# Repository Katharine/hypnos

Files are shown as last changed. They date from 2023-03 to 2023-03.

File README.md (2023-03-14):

Project Hypnos
==============

A hardware controller for the Eight Sleep sleep mattress - because controlling your bed with a phone is a pain.

Turn a knob to adjust the temperature, press the knob to turn it on or off, or to turn off the alarm. Simple!



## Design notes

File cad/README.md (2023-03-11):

# Hypnos CAD files

They're on OnShape, [over here](https://cad.onshape.com/documents/eb943bd92382fa15c7f34176/w/b598a4b6743600d12fabdcd6/e/ee163424c4e488bc4fefc6ba).

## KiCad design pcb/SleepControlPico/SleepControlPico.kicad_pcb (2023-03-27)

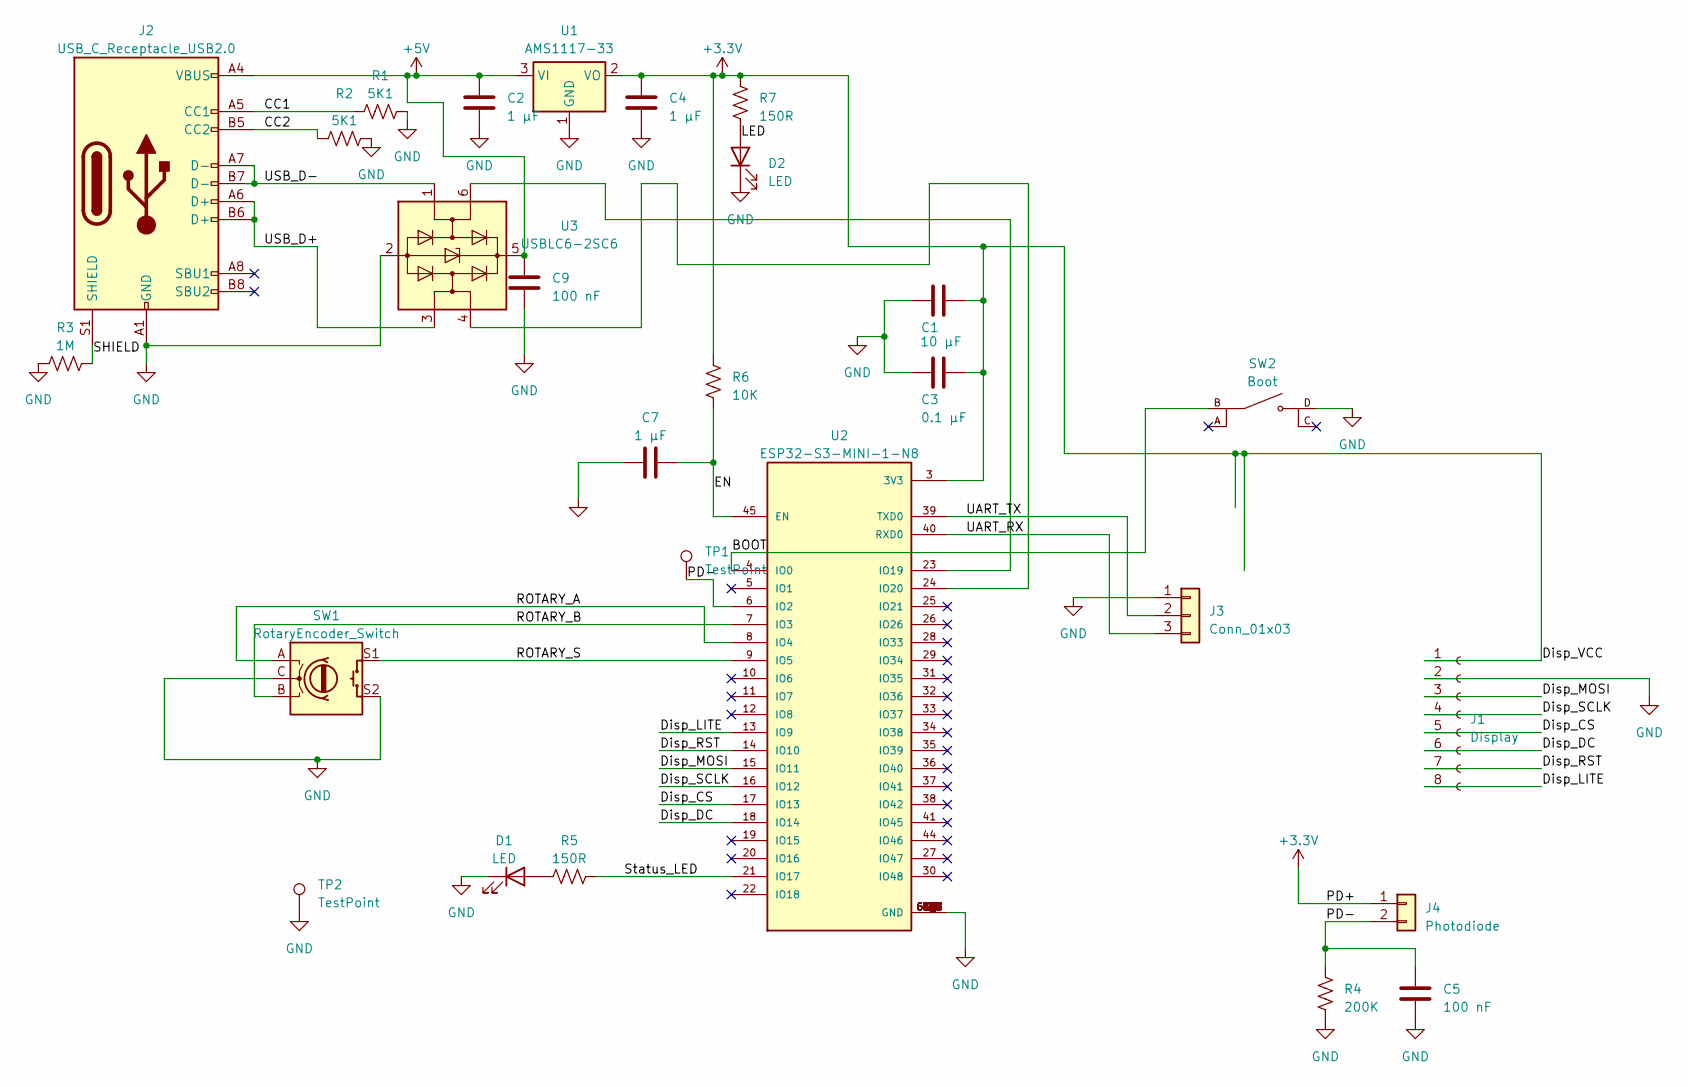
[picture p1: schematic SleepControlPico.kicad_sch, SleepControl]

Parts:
C1: 10 µF; C_0603_1608Metric; LCSC Part # C96446
C2, C4, C7: 1 µF; C_0402_1005Metric; LCSC Part # C52923
C3: 0.1 µF; C_0402_1005Metric; LCSC Part # C307331
C5, C9: 100 nF; C_0402_1005Metric; LCSC Part # C307331
D1, D2: LED; LED_0603_1608Metric; LCSC Part # C2286
J1: Display; JST-B8B-ZR-0; LCSC Part # C493145
J2: USB_C_Receptacle_USB2.0; USB_C_Receptacle_G-Switch_GT-USB-7010ASV; LCSC Part # C2988369
J3: Conn_01x03; PinHeader_1x03_P2.54mm_Horizontal; LCSC Part # C2935928
J4: Photodiode; JST_PH_B2B-PH-K_1x02_P2.00mm_Vertical; LCSC Part # C131337
R1, R2: 5K1; R_0603_1608Metric; LCSC Part # C23186
R3: 1M; R_0603_1608Metric; LCSC Part # C22935
R4: 200K; R_Axial_DIN0207_L6.3mm_D2.5mm_P7.62mm_Horizontal; LCSC Part # C58614
R5: 150R; R_0402_1005Metric; LCSC Part # C25133
R6: 10K; R_0603_1608Metric; LCSC Part # C25804
R7: 150R; R_0402_1005Metric; LCSC Part # C25082
SW1: RotaryEncoder_Switch; Bourns-PEC11R-4020F-S0012-MFG; LCSC Part # C143790
SW2: Boot; SW_TS-1187A-B-A-B; PARTREV A0; LCSC Part # C318884
TP1, TP2: TestPoint; TestPoint_Pad_D1.0mm
U1: AMS1117-33; SOT-223-3_TabPin2; LCSC Part # C6186
U2: ESP32-S3-MINI-1-N8; XCVR_ESP32-S3-MINI-1-N8; PARTREV v0.6; LCSC Part # C2913206
U3: USBLC6-2SC6; SOT-23-6; LCSC Part # C7519

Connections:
+3.3V: C1.1, C3.1, C4.1, J1.1, J4.1, R6.1, R7.1, U1.2 (VO), U2.3 (3V3)
+5V: C2.1, C9.2, J2.A4 (VBUS), J2.A9 (VBUS), J2.B4 (VBUS), J2.B9 (VBUS), U1.3 (VI), U3.5 (VBUS)
/BOOT: SW2.B, U2.4 (IO0)
/CC1: J2.A5 (CC1), R1.1
/CC2: J2.B5 (CC2), R2.1
/Disp_CS: J1.5, U2.17 (IO13)
/Disp_DC: J1.6, U2.18 (IO14)
/Disp_LITE: J1.8, U2.13 (IO9)
/Disp_MOSI: J1.3, U2.15 (IO11)
/Disp_RST: J1.7, U2.14 (IO10)
/Disp_SCLK: J1.4, U2.16 (IO12)
/EN: C7.2, R6.2, U2.45 (EN)
/PD-: C5.2, J4.2, R4.1, TP1.1, U2.6 (IO2)
/ROTARY_A: SW1.A, U2.8 (IO4)
/ROTARY_B: SW1.B, U2.7 (IO3)
/ROTARY_S: SW1.S1, U2.9 (IO5)
/SHIELD: J2.S1 (SHIELD), R3.1
/Status_LED: R5.2, U2.21 (IO17)
/UART_RX: J3.3, U2.40 (RXD0)
/UART_TX: J3.2, U2.39 (TXD0)
/USB_D+: J2.A6 (D+), J2.B6 (D+), U3.3 (I/O2)
/USB_D-: J2.A7 (D-), J2.B7 (D-), U3.1 (I/O1)
GND: C1.2, C2.2, C3.2, C4.2, C5.1, C7.1, C9.1, D1.1 (K), D2.1 (K), J1.2, J2.A1 (GND), J2.A12 (GND), J2.B1 (GND), J2.B12 (GND), J3.1, R1.2, R2.2, R3.2, R4.2, SW1.C, SW1.S2, SW2.D, TP2.1, U1.1 (GND), U2.1 (GND), U2.2 (GND), U2.42 (GND), U2.43 (GND), U2.46 (GND), U2.47 (GND), U2.48 (GND), U2.49 (GND), U2.50 (GND), U2.51 (GND), U2.52 (GND), U2.53 (GND), U2.54 (GND), U2.55 (GND), U2.56 (GND), U2.57 (GND), U2.58 (GND), U2.59 (GND), U2.60 (GND), U2.61 (GND), U2.61_1 (GND), U2.61_2 (GND), U2.61_3 (GND), U2.61_4 (GND), U2.61_5 (GND), U2.61_6 (GND), U2.61_7 (GND), U2.61_8 (GND), U2.62 (GND), U2.63 (GND), U2.64 (GND), U2.65 (GND), U3.2 (GND)
unnamed: D1.2 (A), R5.1
unnamed: D2.2 (A), R7.2
unnamed: U2.23 (IO19), U3.6 (I/O1)
unnamed: U2.24 (IO20), U3.4 (I/O2)

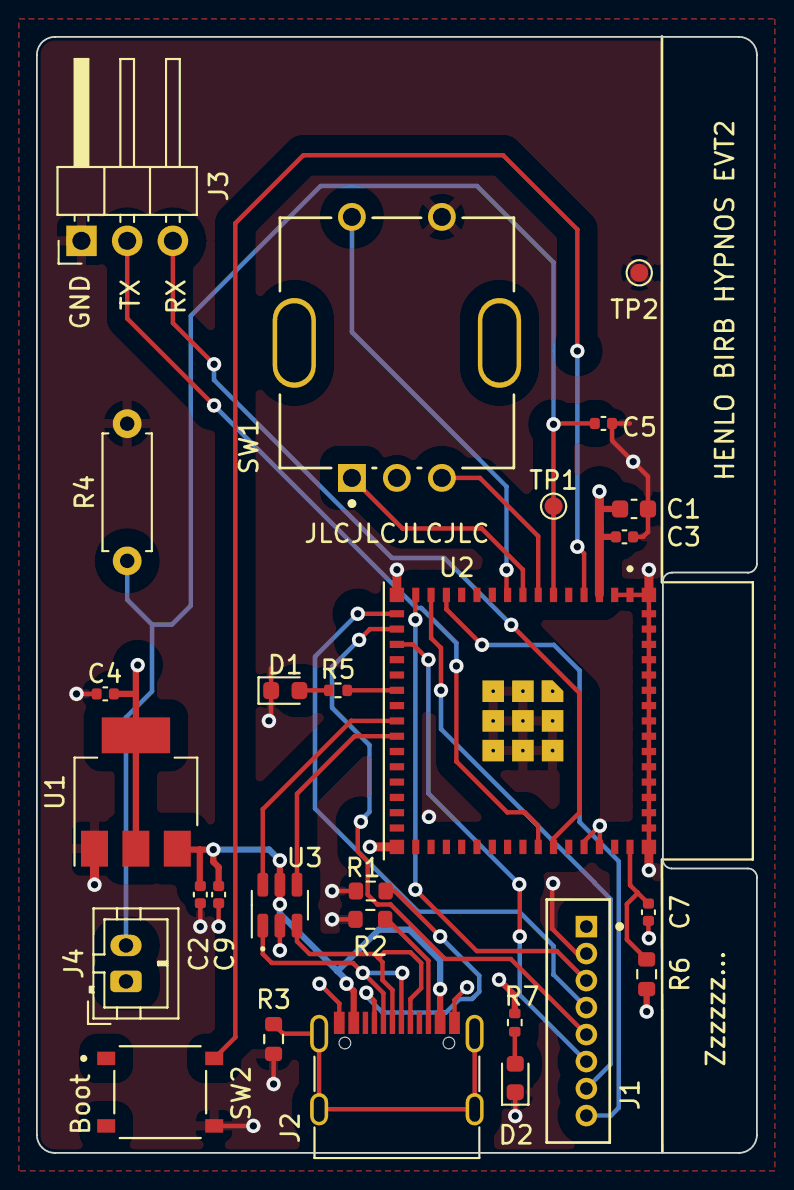
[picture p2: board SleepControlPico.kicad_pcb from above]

Board: 4 copper layers, 40.0 x 62.0 mm, 27 parts (0 on the bottom side), 27 nets.

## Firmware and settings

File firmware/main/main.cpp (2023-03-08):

#include <memory>
#include "apps/root/root_app.h"
#include <esp_log.h>
#include <esp_system.h>
#include <esp_heap_caps.h>
#include <esp_sntp.h>
#include <eightsleep.h>

static std::unique_ptr<apps::root::RootApp> app;

 extern "C" void app_main(void) {
     eightsleep::Client client;

     ESP_LOGI("App", "Free memory: %lu bytes; largest free block: %d bytes.", esp_get_free_heap_size(), heap_caps_get_largest_free_block(MALLOC_CAP_8BIT));

     sntp_setoperatingmode(SNTP_OPMODE_POLL);
     sntp_setservername(0, "time.apple.com");
     sntp_init();

    app = std::make_unique<apps::root::RootApp>();
    app->init();
}

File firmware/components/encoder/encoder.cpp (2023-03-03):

#include "encoder.h"

#include <functional>

#include <driver/gpio.h>
#include <driver/pulse_cnt.h>
#include <esp_log.h>

namespace encoder {

Encoder::Encoder(int a, int b, int button) : a(static_cast<gpio_num_t>(a)), b(static_cast<gpio_num_t>(b)), s(static_cast<gpio_num_t>(button)) {
     gpio_config_t gpiconfig{
         .pin_bit_mask = (1ULL << s),
         .mode = GPIO_MODE_INPUT,
         .pull_up_en = GPIO_PULLUP_ENABLE,
         .pull_down_en = GPIO_PULLDOWN_DISABLE,
//         .intr_type = GPIO_INTR_ANYEDGE,
     };
    ESP_ERROR_CHECK(gpio_config(&gpiconfig));
    // gpio_isr_handler_add(this->a, &handle_isr, this);
    // gpio_isr_handler_add(this->b, &handle_isr, this);
    // gpio_set_direction(this->a, GPIO_MODE_INPUT);
    // gpio_set_direction(this->b, GPIO_MODE_INPUT);

    pcnt_unit_config_t config = {
        .low_limit = -32736,
        .high_limit = 32736,
        .flags = {
            .accum_count = true,
        },
    };
    ESP_ERROR_CHECK(pcnt_new_unit(&config, &pcnt));
    pcnt_glitch_filter_config_t glitch_config = {
        .max_glitch_ns = 12000,
    };
    ESP_ERROR_CHECK(pcnt_unit_set_glitch_filter(pcnt, &glitch_config));
    pcnt_chan_config_t chan_a_config = {
        .edge_gpio_num = a,
        .level_gpio_num = b,
    };
    ESP_ERROR_CHECK(pcnt_new_channel(pcnt, &chan_a_config, &chan_a));
    pcnt_chan_config_t chan_b_config = {
        .edge_gpio_num = b,
        .level_gpio_num = a,
    };
    ESP_ERROR_CHECK(pcnt_new_channel(pcnt, &chan_b_config, &chan_b));

    ESP_ERROR_CHECK(pcnt_channel_set_edge_action(chan_a, PCNT_CHANNEL_EDGE_ACTION_DECREASE, PCNT_CHANNEL_EDGE_ACTION_INCREASE));
    ESP_ERROR_CHECK(pcnt_channel_set_level_action(chan_a, PCNT_CHANNEL_LEVEL_ACTION_KEEP, PCNT_CHANNEL_LEVEL_ACTION_INVERSE));
    ESP_ERROR_CHECK(pcnt_channel_set_edge_action(chan_b, PCNT_CHANNEL_EDGE_ACTION_INCREASE, PCNT_CHANNEL_EDGE_ACTION_DECREASE));
    ESP_ERROR_CHECK(pcnt_channel_set_level_action(chan_b, PCNT_CHANNEL_LEVEL_ACTION_KEEP, PCNT_CHANNEL_LEVEL_ACTION_INVERSE));

    ESP_ERROR_CHECK(pcnt_unit_add_watch_point(pcnt, config.low_limit));
    ESP_ERROR_CHECK(pcnt_unit_add_watch_point(pcnt, config.high_limit));

    pcnt_unit_enable(pcnt);
    pcnt_unit_clear_count(pcnt);
    pcnt_unit_start(pcnt);
}

int Encoder::position() {
    int count;
    ESP_ERROR_CHECK(pcnt_unit_get_count(pcnt, &count));
    return count / 4;
}

bool Encoder::is_button_pressed() {
    int button_state = gpio_get_level(s);
    return !button_state;
}

Encoder::Encoder(Encoder &&other) noexcept : a(other.a), b(other.b), s(other.s) {
    pcnt = other.pcnt;
    chan_a = other.chan_a;
    chan_b = other.chan_b;
    other.pcnt = nullptr;
    other.chan_a = nullptr;
    other.chan_b = nullptr;
}

}

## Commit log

2023-02-23 Initial commit. Just screwing around.
    My C++ is so rusty.
2023-02-24 Use interrupts for spinning the knob.
2023-02-28 Switch to graphical OLED display.
2023-02-28 Add initial PCB draft for posterity
    [SleepControlPico.kicad_pcb, SleepControlPico.kicad_sch]
2023-02-28 start over on firmware, now with 100% less arduino
2023-03-03 Adventures in ESP32 land.
2023-03-03 Smaller PCB using an ESP32-S3-MINI-1.
    [SleepControlPico.kicad_pcb, SleepControlPico.kicad_sch]
2023-03-05 Config works all the way through verified login.
    Revived the Eight Sleep API client from the old Arduino version.
    The mashup of the old and new is not great; more work needed.
    But you can log in! It works!!!
2023-03-05 See if locking LVGL usage stops the verifier from crashing.
    [lvgl_port.cpp]
2023-03-06 More stuff.
    - Actually fetch the current bed status
    - A custom, vaguely-animated widget!
    - Bigger (2 MB) app partitions, because we're out of space.
    - OTA partitions. We need an 8 MB flash between these changes.
    [partitions.csv]
2023-03-07 Incredibly basic backlight control.
    Using a phototransistor (currently set up in a voltage divider with a
    200 kΩ resistor on pin 6), pick some numbers based on the voltage
    picked up by the ADC (and blast to 100% if it's saturated).
    Also manually reset the screen on boot. You'd think esp_lcd_panel_reset
    would do that, but it doesn't.
    [backlight.cpp, lvgl_port.cpp]
2023-03-07 Pretend to control your bed!
    - Fetches and maintains actual bed state from the internet
    - Lets you spin the knob (to no avail)
    - Snaps display back to real targets if they change
    - Regularly reauths and updates bed state.
2023-03-08 Fix the time log under newlib-nano.
    [main.cpp]
2023-03-08 Now actually controls the real bed!
2023-03-10 add tiny PCB to attach the photodiode
    [Photodiode.kicad_pcb, Photodiode.kicad_sch]
2023-03-11 Final-ish PCB layout
    [SleepControlPico.kicad_pcb, SleepControlPico.kicad_sch]
2023-03-11 remove accelerometer (out of stock)
    [SleepControlPico.kicad_pcb, SleepControlPico.kicad_sch]
2023-03-11 Final(?) PCB revision.
    [SleepControlPico.kicad_pcb, SleepControlPico.kicad_sch]
2023-03-11 Try to fix the state thread sometimes getting wedged.
2023-03-12 Add tick marks to the main UI.
    Tick marks indicate:
    - The current target
    - The bed's current target, if it's different
    - The bed's actual temperature
    Also some bug fixes that caused the actual temperature to be wrong.
2023-03-17 Pull out a screen stack.
    Instead of explicitly managing screens and groups everywhere always,
    have a stack of screens that can be pushed, popped, or replaced.
    As part of this, the shared_ptrs to all the common parts have been
    extracted into some statics that everything can freely reference.
    [backlight.cpp]
2023-03-27 update config to reflect real board setup
2023-03-27 Fix wrong resistor part
    [SleepControlPico.kicad_pcb]
2023-03-27 Fix USB D+ and D- lines being switched
    [SleepControlPico.kicad_pcb, SleepControlPico.kicad_sch]
